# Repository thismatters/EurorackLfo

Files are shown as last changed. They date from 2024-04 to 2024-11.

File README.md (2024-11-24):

# Low Frequency Oscillator

The Low Frequency Oscillator (LFO), as the name implies, oscillates at a low frequency. This implementation operates over a wide frequency range enabled by a rate knob and switch, offers access to 4 wave shapes simultaneously, and can be synced with an external clock.

The circuit here is based on the [Yusynth LFO 2](https://yusynth.net/Modular/EN/LFO/VC-LFO2.html) with minor tweaks to make it more Eurorack friendly. The changes I've made are thus:
* Selected resistors appropriate for +/-12V rails,
* Added polarity protection so that a backward power header doesn't fry anything (twin series schotty diodes: BAT54SL),
* Selected a modern dual NPN diode package for matched transistors,
* Full surface mount design.

The Yusynth page is a treasure trove of information about this circuit that I am too amateur to claim as my own; please read that outstanding page before using this circuit. The page provides many details and other implementations of this circuit that you may find suitable.

The KiCAD project here uses the library/footprints [found in my companion repo](https://github.com/thismatters/EurorackKiCAD).

## Width

6hp on a standard 3U rack.

## Inputs

Potentiometer labeled `rate` controls oscillation rate along with toggle switch to flip between `fast` and `slow`. Single `cv` input allows modulation of rate, which is augmented by a potentiometer labeled `cv`. Potentiometer labeled `pwm` adjusts the duty cycle for the square wave output. Oscillation can be synced to an external input by way of the `sync` input.

## Output

Four outputs, one for each of the following waveshapes: Sine, Saw, Triangle, Rectangle.
An LED visualizes the square wave output.

## Adjustment

You'll need an oscilloscope.

1. Set the `cv` knob to minimum.
1. Set the range switch to `slow`.
1. Set the `rate` knob to minimum.
1. Adjust RV4 until the LED blinks on every 10 seconds (0.1Hz)
1. Set the `rate` knob to maximum.
1. Connect the oscilloscope to the SAW output (sharp rising edge, ramp to low).
1. Adjust RV6 until the SAW output covers the -5V to 5V range.
1. Connect the oscilloscope to the TRIANGLE output.
1. Adjust RV7 until the TRIANGLE output covers the -5V to 5V range.
1. Connect the oscilloscope to the SINE output.
1. Adjust RV7 to perfect the SINE shape.
1. Set the range switch to `fast`.
1. Connect the oscilloscope to the TRIANGLE output.
1. Adjust RV5 to get a symmetric wave shape.

## Vendors

There are part numbers in the [BOM](lfo.csv) for many of the parts (not for basic passives though) at the following vendors:

* [Mouser](https://www.mouser.com): Needs no introduction. Get your ICs from here (or [digikey](https://www.digikey.com)).
* [Tayda Electronics](https://www.taydaelectronics.com/): Good supplier for passive components; audio jacks, and potentiometers. Their audio jacks are slightly smaller than the thonkiconn from thonk.
* [Love My Switches](https://lovemyswitches.com/): Has [really good knobs](https://lovemyswitches.com/anodized-aluminum-knob-the-lo-fi-1-4-smooth-shaft-12-5mm-od/) to go on those potentiometers!
* [OSHPark](https://oshpark.com/): Fast and (relatively) cheap PCB manufacturer. The [V0 circuit](https://oshpark.com/shared_projects/wfHu28zj) works well but has several bugs which are listed below.

# Bugs

## V0
* CV knob is backwards
* PWM knob is backwards
* Rate knob is backwards
* Kinda hard to dial in

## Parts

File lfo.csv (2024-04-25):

# | Reference | Qty | Value | Footprint | DNP | Vendor | PartNum
1 | C1, C2 | 2 | 22u/35V | Capacitor_THT:CP_Radial_D5.0mm_P2.50mm
2 | C3, C6 | 2 | 10n | Capacitor_SMD:C_0805_2012Metric
3 | C4 | 1 | 47n | Capacitor_SMD:C_0805_2012Metric
4 | C5, C11, C12 | 3 | 100n | Capacitor_SMD:C_0805_2012Metric
5 | C7 | 1 | 10u/35V | Capacitor_THT:CP_Radial_D5.0mm_P2.50mm
6 | C8 | 1 | 1u/35V | Capacitor_THT:CP_Radial_D5.0mm_P2.50mm
7 | C9 | 1 | 120p | Capacitor_SMD:C_0603_1608Metric_Pad1.08x0.95mm_HandSolder
8 | C10 | 1 | 1n | Capacitor_SMD:C_0805_2012Metric
9 | D1, D2, D3, D4 | 4 | 1N4148 | Diode_SMD:D_SOD-323_HandSoldering
10 | D5, D6 | 2 | BAT54S | Package_TO_SOT_SMD:SOT-23 |  | Mouser | 863-BAT54SLT1G
11 | D7 | 1 | LED | LED_THT:LED_D3.0mm
12 | J1 | 1 | Conn_02x05_Odd_Even | Eurorack:PinHeader_2x05_P2.54mm_Vertical |  | Tayda | A-2939
13 | J2, J3, J4, J5, J6, J7 | 6 | AudioJack2_SwitchT | Eurorack:AudioJack2_Tayda_A-2566 |  | Tayda | A-2566
14 | Q1 | 1 | BC557 | Package_TO_SOT_THT:TO-92_Inline_Wide |  | Mouser | 637-BC557B
15 | Q2 | 1 | BS170 | Package_TO_SOT_THT:TO-92_Inline_Wide |  | Mouser | 512-BS170
16 | Q3 | 1 | BC547 | Package_TO_SOT_THT:TO-92_Inline_Wide |  | Mouser | 637-BC547C
17 | R1, R2 | 2 | 10 | Resistor_SMD:R_0805_2012Metric
18 | R3, R18, R34 | 3 | 10K | Resistor_SMD:R_0805_2012Metric
19 | R4, R6, R7, R9, R11, R14, R15, R19, R20, R21, R31, R32 | 12 | 100K | Resistor_SMD:R_0805_2012Metric
20 | R5, R25, R30, R33, R36, R40 | 6 | 1K | Resistor_SMD:R_0805_2012Metric
21 | R8 | 1 | 12K | Resistor_SMD:R_0805_2012Metric
22 | R10 | 1 | 8.2K | Resistor_SMD:R_0805_2012Metric
23 | R12 | 1 | 27K | Resistor_SMD:R_0805_2012Metric
24 | R13 | 1 | 820 | Resistor_SMD:R_0805_2012Metric
25 | R16 | 1 | 2.7K | Resistor_SMD:R_0805_2012Metric
26 | R17, R23 | 2 | 200K | Resistor_SMD:R_0805_2012Metric
27 | R22 | 1 | 50K | Resistor_SMD:R_0805_2012Metric
28 | R24, R26 | 2 | 150K | Resistor_SMD:R_0805_2012Metric
29 | R27 | 1 | 22K | Resistor_SMD:R_0805_2012Metric
30 | R28, R37, R38 | 3 | 15K | Resistor_SMD:R_0805_2012Metric
31 | R29 | 1 | 1.5K | Resistor_SMD:R_0805_2012Metric
32 | R35 | 1 | 4.7K | Resistor_SMD:R_0805_2012Metric
33 | R39 | 1 | 47K | Resistor_SMD:R_0805_2012Metric
34 | RV1, RV3 | 2 | B10K | Eurorack:Potentiometer_RV16AF-41-15R1 |  | Tayda | A-2969
35 | RV2 | 1 | B50K | Eurorack:Potentiometer_RV16AF-41-15R1 |  | Tayda | A-5401
36 | RV4, RV7 | 2 | 50K | Potentiometer_THT:Potentiometer_Bourns_3296W_Vertical
37 | RV5, RV6 | 2 | 10K | Potentiometer_THT:Potentiometer_Bourns_3296W_Vertical
38 | SW1 | 1 | SW_DPDT_x2 | Eurorack:Switch_DPDT_Tayda_A-5752 |  | Tayda | A-6809
39 | U1 | 1 | ICM7555xB | Package_SO:SOIC-8_3.9x4.9mm_P1.27mm |  | Mouser | 968-ICM7555CBAZ-T
40 | U2, U3 | 2 | TL074 | Package_SO:SOIC-14_3.9x8.7mm_P1.27mm |  | Mouser | 595-TL074CN

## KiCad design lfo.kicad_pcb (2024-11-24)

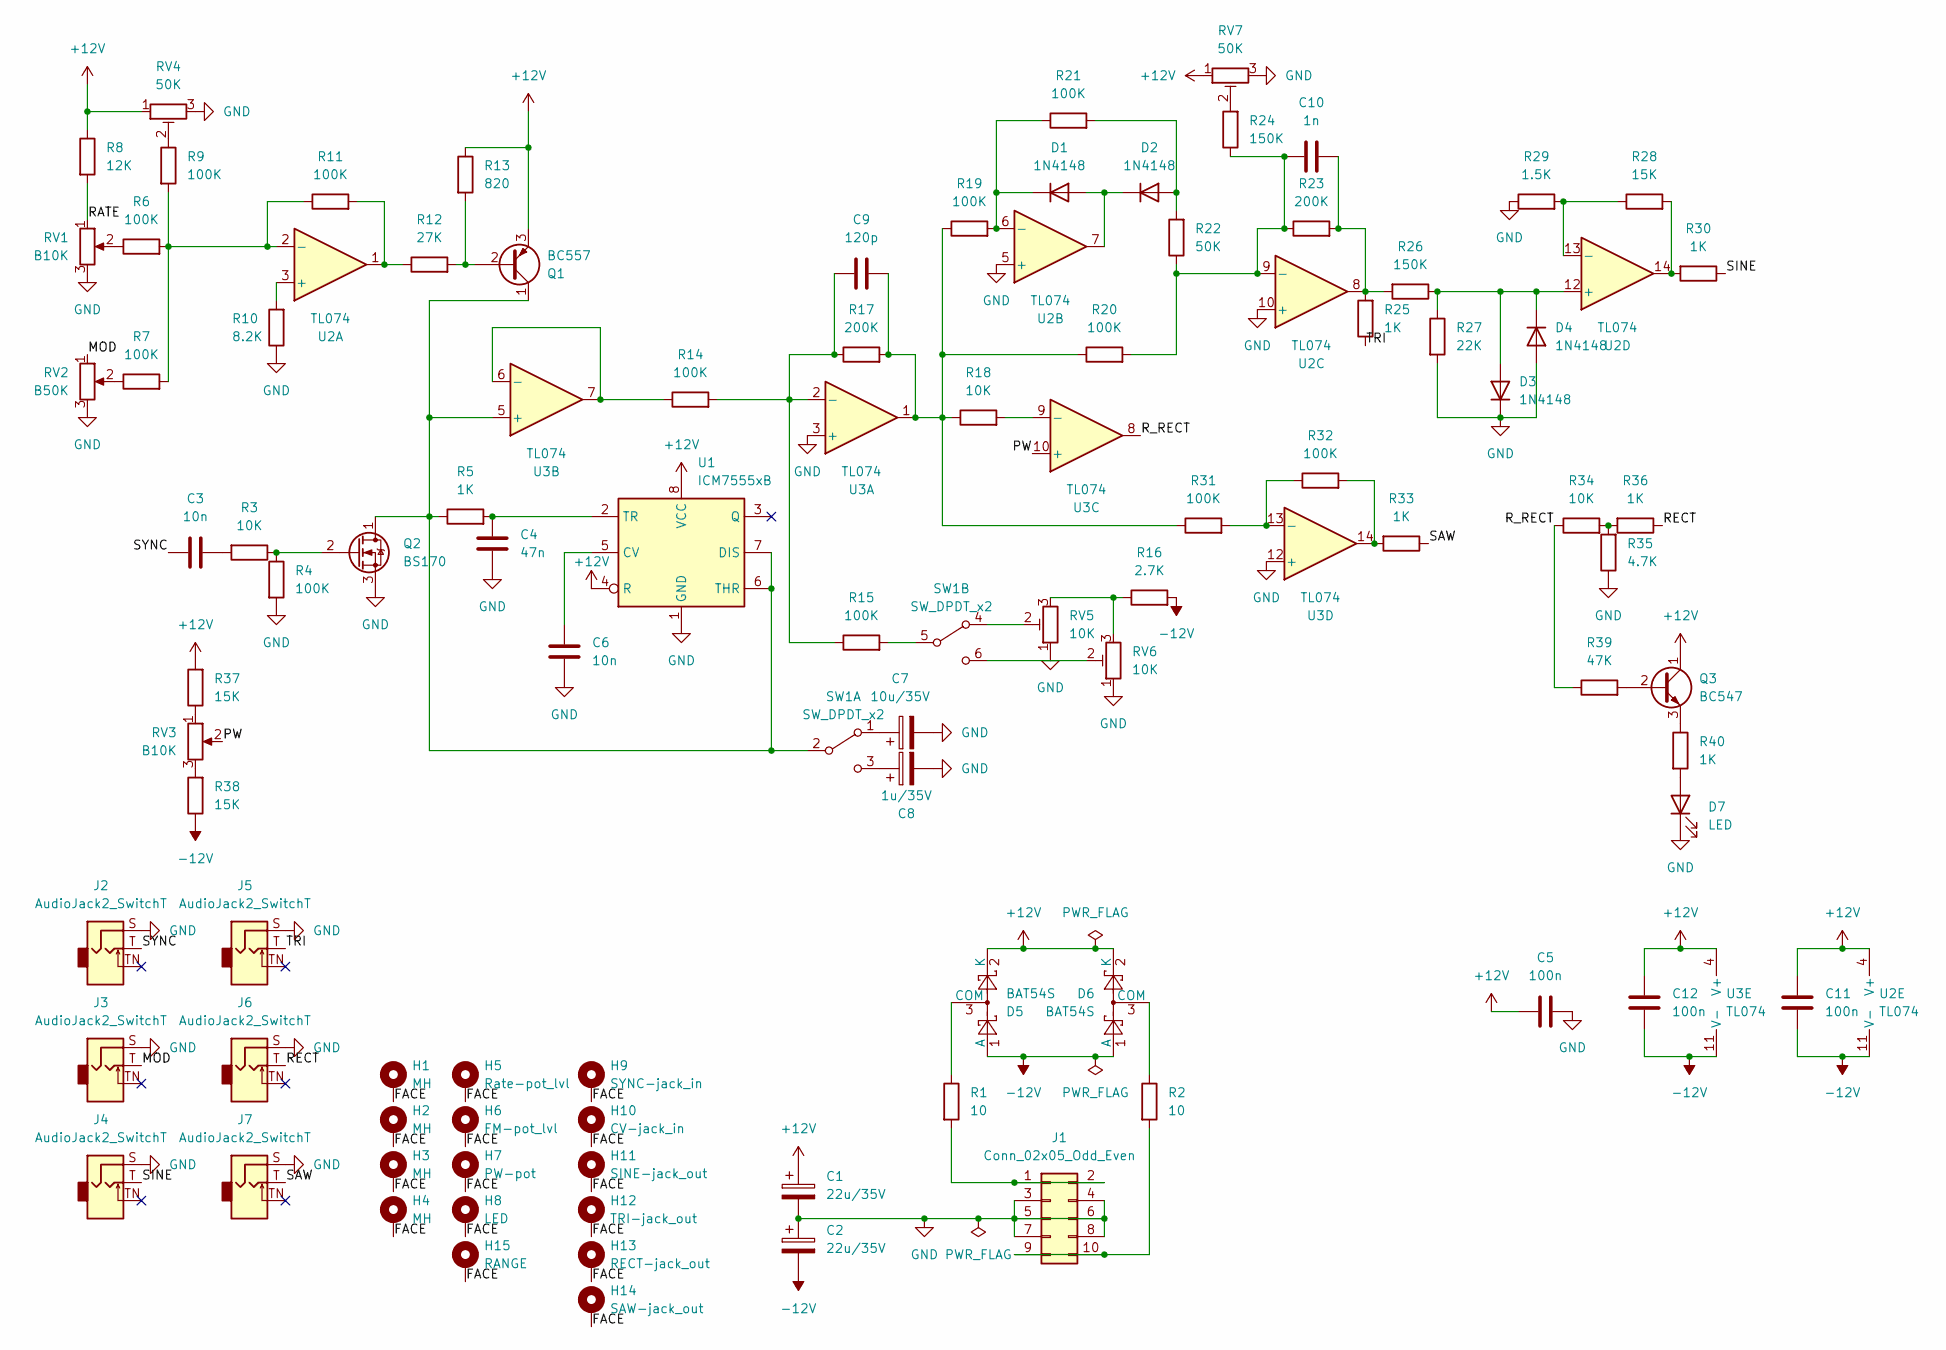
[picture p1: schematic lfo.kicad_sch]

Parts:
C1, C2: 22u/35V; CP_Radial_D5.0mm_P2.50mm
C3, C6: 10n; C_0805_2012Metric
C4: 47n; C_0805_2012Metric
C5, C11, C12: 100n; C_0805_2012Metric
C7: 10u/35V; CP_Radial_D5.0mm_P2.50mm
C8: 1u/35V; CP_Radial_D5.0mm_P2.50mm
C9: 120p; C_0603_1608Metric_Pad1.08x0.95mm_HandSolder
C10: 1n; C_0805_2012Metric
D1, D2, D3, D4: 1N4148; D_SOD-323_HandSoldering
D5, D6: BAT54S; SOT-23; PartNum 863-BAT54SLT1G
D7: LED; LED_D3.0mm
H1, H2, H3, H4: MH; Mech-MountingHole
H5: Rate-pot_lvl; Mech-Potentiometer-Hole_level
H6: FM-pot_lvl; Mech-Potentiometer-Hole_level
H7: PW-pot; Mech-Potentiometer-Hole_pan
H8: LED; Mech-LED-Hole-3mm-Bezel
H9: SYNC-jack_in; Mech-AudioJack-Hole
H10: CV-jack_in; Mech-AudioJack-Hole
H11: SINE-jack_out; Mech-AudioJack-Hole-Output
H12: TRI-jack_out; Mech-AudioJack-Hole-Output
H13: RECT-jack_out; Mech-AudioJack-Hole-Output
H14: SAW-jack_out; Mech-AudioJack-Hole-Output
H15: RANGE; Mech-2M_Switch-Hole
J1: Conn_02x05_Odd_Even; PinHeader_2x05_P2.54mm_Vertical; PartNum A-2939
J2, J3, J4, J5, J6, J7: AudioJack2_SwitchT; AudioJack2_Tayda_A-2566; PartNum A-2566
Q1: BC557; TO-92_Inline_Wide; PartNum 637-BC557B
Q2: BS170; TO-92_Inline_Wide; PartNum 512-BS170
Q3: BC547; TO-92_Inline_Wide; PartNum 637-BC547C
R1, R2: 10; R_0805_2012Metric
R3, R18, R34: 10K; R_0805_2012Metric
R4, R6, R7, R9, R11, R14, R15, R19, R20, R21, R31, R32: 100K; R_0805_2012Metric
R5, R25, R30, R33, R36, R40: 1K; R_0805_2012Metric
R8: 12K; R_0805_2012Metric
R10: 8.2K; R_0805_2012Metric
R12: 27K; R_0805_2012Metric
R13: 820; R_0805_2012Metric
R16: 2.7K; R_0805_2012Metric
R17, R23: 200K; R_0805_2012Metric
R22: 50K; R_0805_2012Metric
R24, R26: 150K; R_0805_2012Metric
R27: 22K; R_0805_2012Metric
R28, R37, R38: 15K; R_0805_2012Metric
R29: 1.5K; R_0805_2012Metric
R35: 4.7K; R_0805_2012Metric
R39: 47K; R_0805_2012Metric
RV1, RV3: B10K; Potentiometer_RV16AF-41-15R1; PartNum A-2969
RV2: B50K; Potentiometer_RV16AF-41-15R1; PartNum A-5401
RV4, RV7: 50K; Potentiometer_Bourns_3296W_Vertical
RV5, RV6: 10K; Potentiometer_Bourns_3296W_Vertical
SW1: SW_DPDT_x2; Switch_DPDT_Tayda_A-5752; PartNum A-6809
U1: ICM7555xB; SOIC-8_3.9x4.9mm_P1.27mm; PartNum 968-ICM7555CBAZ-T
U2, U3: TL074; SOIC-14_3.9x8.7mm_P1.27mm; PartNum 595-TL074CN

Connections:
+12V: C1.1, C5.1, C11.1, C12.1, D5.2 (K), D6.2 (K), Q1.3 (E), Q3.1 (C), R8.1, R13.1, R37.2, RV4.1, RV7.1, U1.4 (R), U1.8 (VCC), U2.4 (V+), U3.4 (V+)
-12V: C2.2, C11.2, C12.2, D5.1 (A), D6.1 (A), R16.2, R38.1, U2.11 (V-), U3.11 (V-)
/FACE: H1.1, H2.1, H3.1, H4.1, H5.1, H6.1, H7.1, H8.1, H9.1, H10.1, H11.1, H12.1, H13.1, H14.1, H15.1
/MOD: J3.T, RV2.1
/PW: RV3.2, U3.10 (+)
/RATE: R8.2, RV1.1
/RECT: J6.T, R36.1
/R_RECT: R34.1, R39.1, U3.8
/SAW: J7.T, R33.1
/SINE: J4.T, R30.1
/SYNC: C3.1, J2.T
/TRI: J5.T, R25.1
GND: C1.2, C2.1, C4.1, C5.2, C6.2, C7.2, C8.2, D3.1 (K), D4.2 (A), D7.1 (K), J1.3, J1.4, J1.5, J1.6, J1.7, J1.8, J2.S, J3.S, J4.S, J5.S, J6.S, J7.S, Q2.3 (S), R4.2, R10.1, R27.2, R29.1, R35.1, RV1.3, RV2.3, RV4.3, RV5.1, RV6.1, RV7.3, U1.1 (GND), U2.5 (+), U2.10 (+), U3.3 (+), U3.12 (+)
unnamed: C3.2, R3.2
unnamed: C9.2, R17.2, R18.1, R19.1, R20.1, R31.1, U3.1
unnamed: C10.2, R23.2, R25.2, R26.2, U2.8
unnamed: D1.2 (A), D2.1 (K), U2.7
unnamed: D1.1 (K), R19.2, R21.1, U2.6 (-)
unnamed: D2.2 (A), R21.2, R22.2
unnamed: D3.2 (A), D4.1 (K), R26.1, R27.1, U2.12 (+)
unnamed: D5.3 (COM), R1.1
unnamed: D6.3 (COM), R2.1
unnamed: D7.2 (A), R40.2
unnamed: J1.1, J1.2, R1.2
unnamed: J1.9, J1.10, R2.2
unnamed: Q1.2 (B), R12.2, R13.2
unnamed: Q1.1 (C), Q2.1 (D), R5.1, SW1.2 (B), U1.6 (THR), U1.7 (DIS), U3.5 (+)
unnamed: Q2.2 (G), R3.1, R4.1
unnamed: Q3.2 (B), R39.2
unnamed: Q3.3 (E), R40.1
unnamed: R6.1, RV1.2
unnamed: R7.1, RV2.2
unnamed: R9.1, RV4.2
unnamed: R11.2, R12.1, U2.1
unnamed: R16.1, RV5.3, RV6.3
unnamed: R24.2, RV7.2
unnamed: R28.2, R30.2, U2.14
unnamed: R32.2, R33.2, U3.14
unnamed: R34.2, R35.2, R36.2
unnamed: R37.1, RV3.1
unnamed: R38.2, RV3.3
unnamed: C7.1, SW1.1 (A)
unnamed: C8.1, SW1.3 (C)
unnamed: RV5.2, SW1.4 (A)
unnamed: R15.2, SW1.5 (B)
unnamed: RV6.2, SW1.6 (C)
unnamed: C6.1, U1.5 (CV)
unnamed: C4.2, R5.2, U1.2 (TR)
unnamed: R10.2, U2.3 (+)
unnamed: R6.2, R7.2, R9.2, R11.1, U2.2 (-)
unnamed: C10.1, R20.2, R22.1, R23.1, R24.1, U2.9 (-)
unnamed: R28.1, R29.2, U2.13 (-)
unnamed: C9.1, R14.2, R15.1, R17.1, U3.2 (-)
unnamed: R14.1, U3.6 (-), U3.7
unnamed: R18.2, U3.9 (-)
unnamed: R31.2, R32.1, U3.13 (-)

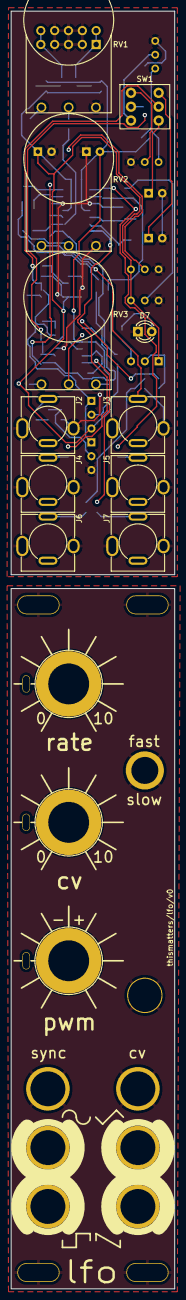
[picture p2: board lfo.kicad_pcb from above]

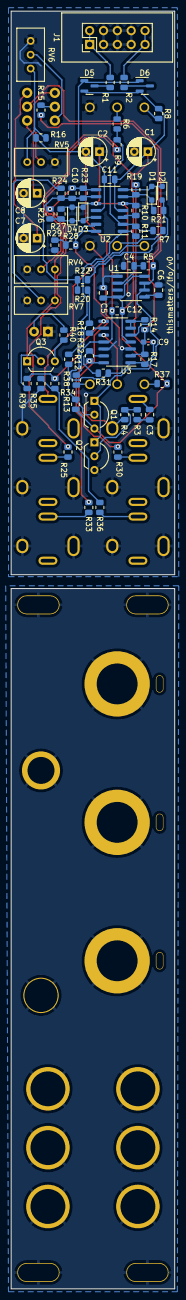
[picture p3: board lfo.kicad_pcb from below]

Board: 2 copper layers, 30.0 x 234.4 mm, 95 parts (69 on the bottom side), 56 nets.

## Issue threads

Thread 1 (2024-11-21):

status of the euro modules?

KeLaiFu, 2024-11-21:
I've been meaning to ask this for a long time, not sure if I asked and then forgot about it so apologies if you've already answered on another repo...but...
Would it be possible to add a status on the repos so we know which ones are ready to be fabricated?
I'm keen to built the yusynth LFO and a few of the others, so would appreciate conformation it should work once its built and problems I may have are down to my shonky soldering.

Cheers

thismatters, 2024-11-22:
Absolutely! I've been going back through the individual repos and updating the "Vendors" section to link boards that work without having to do any hacking, but I'm a little behind. I've been considering adding a top level repo for which each eurorack module would be (appropriately) a git submodule, but I haven't gotten to it yet.

thismatters, 2024-11-22:
The [VCO circuit](https://github.com/thismatters/EurorackVco) has a link to OSHPark to get PCBs made. I will probably be revising that soon because some aspects are not perfectly functional (PWM range is kinda broken, sine shape could be better), but overall it works.

KeLaiFu, 2024-11-24:
fantastic! watching those 1U modules too, I have a lot of 1U space to fill.

thismatters, 2024-11-25:
Alright. I went through and updated all the repos for which prototypes have been made. Only one circuit is cursed right now (so don't build the mult... how I messed up the simplest possible module is beyond me, but I managed it :).

Also I added [this new status repo](https://github.com/thismatters/Eurorack) so you can get an birds-eye view of the project.

Closed 2024-11-25.

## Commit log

2024-04-25 updating bom
    [lfo.csv, lfo.kicad_sch]
2024-04-25 fix pcb
    [lfo.kicad_pcb]
2024-11-24 annotating some issues
    [lfo.kicad_pcb]
